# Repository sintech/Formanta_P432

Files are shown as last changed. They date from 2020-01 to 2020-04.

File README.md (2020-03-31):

# Форманта П432
инструкция ([djvu](docs/Formanta%20P432%20Users%20manual.djvu) | [pdf](docs/Formanta%20P432%20Users%20manual.pdf)), [схемы](schematic), [прошивки](roms) и [эмулятор](src).

Устройство для проверки узла генераторов - [Cхема PDF](kicad/OscTester/OscTester.pdf)

Инструкция по доработке узла генераторов до последней известной версии - [PDF](docs/Oscillator_board_upgrade_tips.pdf)

# Formanta P432 # 
[Manual](docs/Formanta%20P432%20Users%20manual.pdf), [schematic diagrams](schematic), [ROM dumps](roms) and [emulator](src).

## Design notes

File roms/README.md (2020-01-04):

## Узел генераторов ##
* **DD1.BIN**, **DD2.BIN** - частота-приращение
* **DD13.BIN**, **DD14.BIN**, **DD18.BIN**, **DD19.BIN** - волноформы
* **DD27.BIN**, **DD28.BIN** - масштабирование

## Узел процессора ##
**DD16.BIN** - ПО синтезатора, конфигурация тембров (с адреса 0x400).

## Узел МИДИ-интерфейса ##
**Midi_DD2.BIN** - подпрограммы МИДИ

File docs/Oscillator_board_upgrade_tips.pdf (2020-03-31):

## Инструкция по приведению узла генераторов Форманты П432 к последней

известной версии.

Известные мне печатные платы узла генераторов с децимальным номером ДПЮ 7.102.087 имеют следующие даты изготовления и заводские номера:

- П432, изм. 10, дата 04-91, №290 (ранняя версия, без платы ПНЧ (преобразователя напряжениечастота)
- П432, изм. 10, дата 10-91, №137-2 (с платой ПНЧ)
- П432, изм. 10, дата 11-91, №137-6 (с платой ПНЧ)
- П432, изм. 10, дата 12-91, №56-8 (с платой ПНЧ)
- П432, изм. 15, дата 09-92, №1143-2 (новая топология, с платой ПНЧ)
- МИНИ, изм. 14, дата 07-92, №881-14 (новая топология, с платой ПНЧ)

Существует минимум две версии топологии платы. Ранняя имеет следующие признаки:

- От анода VD12(обозначение на плате) идет дорожка к 6 выводу DD15 (перерезана)
- VT5-К, катод VD7 и левый вывод C18 соединены (может быть перерезано)
- Дорожка от DD29-5 до DD21-1 (может быть перерезана)

Список шагов актуален для версии узла генераторов с подключенной дочерней платой ПНЧ.

В приложении приведены фотографии плат с обозначением мест доработок.

### Список шагов

Удалить элементы:
1. Конденсаторы: C34(470uF), С35(H24), С36(n27), С10?
2. Транзистор VT5
3. Резисторы: R41(75к)? (34к у меня), R38(68к)
4. Подстроечный резистор R64 (баланс DA49).
5. Диод поверх R36 (черная полоса к DA49).

Перерезать дорожки:
1. Над R43, соединяющую DA38-18 и VT5-Б
2. Соединяющую DD47-8 и R66
3. Соединяющую катод VD12(обозначение на плате) и DD15-6
4. Соединяющую VT5-К, катод VD7 и левый вывод C18.
5. Соединяющую DD29-5 и DD21-1.
6. Между соединением R66 и R40 (на обратной стороне)
7. Соединяющую DD46-16 и +5В (обратная сторона)
8. Соединяющую DD47-10 и C18+VT5-Э (обратная сторона)
9. От шины земли до DD39-10 (обратная сторона)
10. Соединяющую R14 и DA17-6 (обратная сторона)
11. Соединяющую DD21-1 и DD21-5 (обратная сторона)

Добавить элементы:
1. Добавить резистор 330Ом от DD46-16 до +5В (с обратной)
2. Резистор (R71) 47к между DD39-7(GNDD) и DD39-10. Конденсатор (С40) 10мкФ между DD39-10 и +5В.
3. Резистор 100кОм в точки, где стоял проволочный фиксатор C34.
4. Транзистор VT5 – КТ3102, развернув его на 180о относительно старого.
5. Конденсатор 68нФ от соединения R41+C35+C36 до точки R41+DA49-3.

6. Конденсатор 270пФ поверх R39.
7. Транзистор КП103Е. Исток – DA49-2(1 вывод R38), сток – DA47-3(2 вывод R38), затвор – R41+C35.
8. Заменить R66 на 33кОм.

Установить перемычки на обратной стороне платы:
1. От соединения R26 и R23 до DA48-4 (заводская?, может быть сверху)
2. От катода VD12 до DD29-5
3. Катод VD7 до DA41-3
4. От R14 (со стороны пореза) до катода VD9(напротив DD21-1) + R65 + R12.
5. От DD47-10 до DD47-8+C18+VT5-К
6. От точки 35 (Усилитель ОУ0) до свободного вывода R66
7. От свободного вывода R40 до + бывшего С34 (+5В)
8. От соединения C36, C35 до первого вывода резистора 100к, от второго вывода до C18+VT5-Э
9. DD21-5 и DD29-5 (к ноге R67)

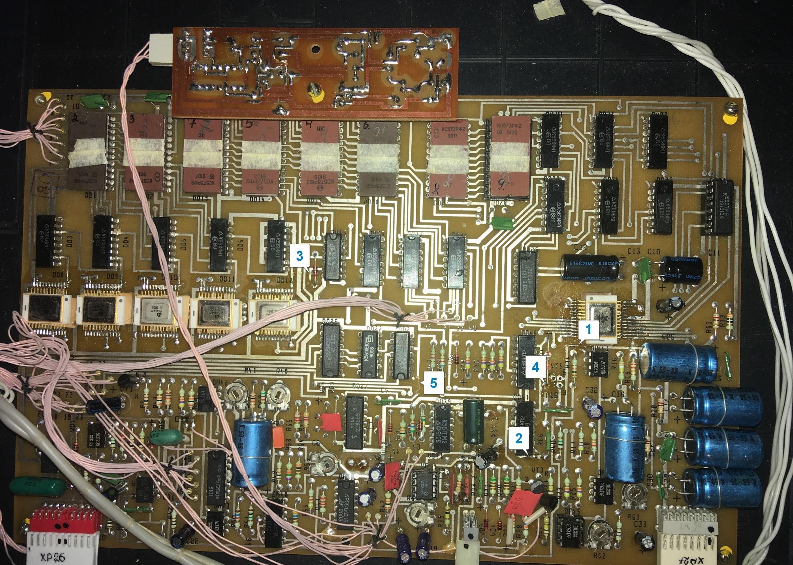
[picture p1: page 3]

### Приложение

Перерезать дорожки сверху

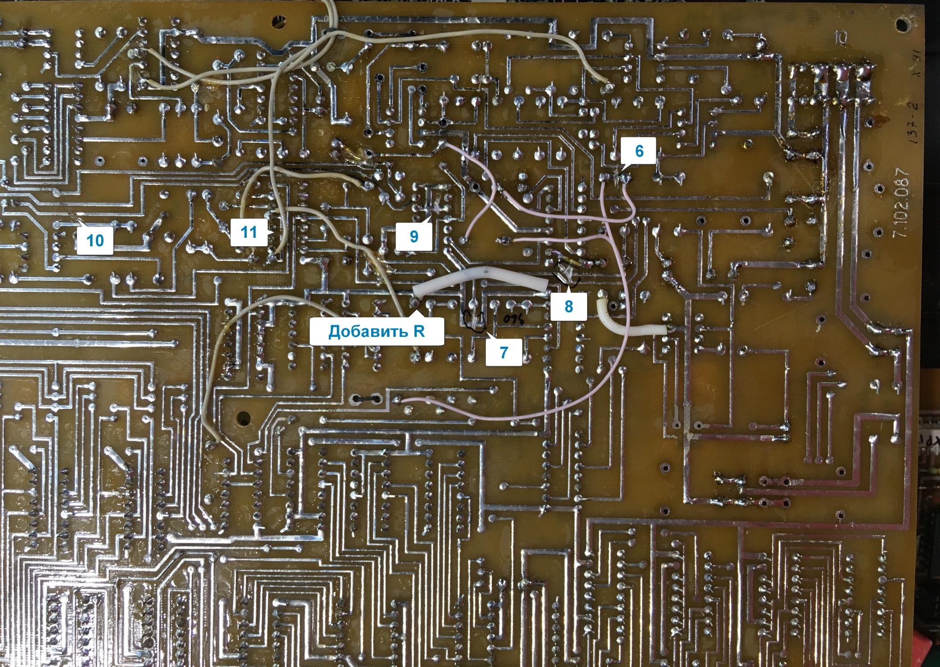
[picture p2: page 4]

Перерезать дорожки снизу

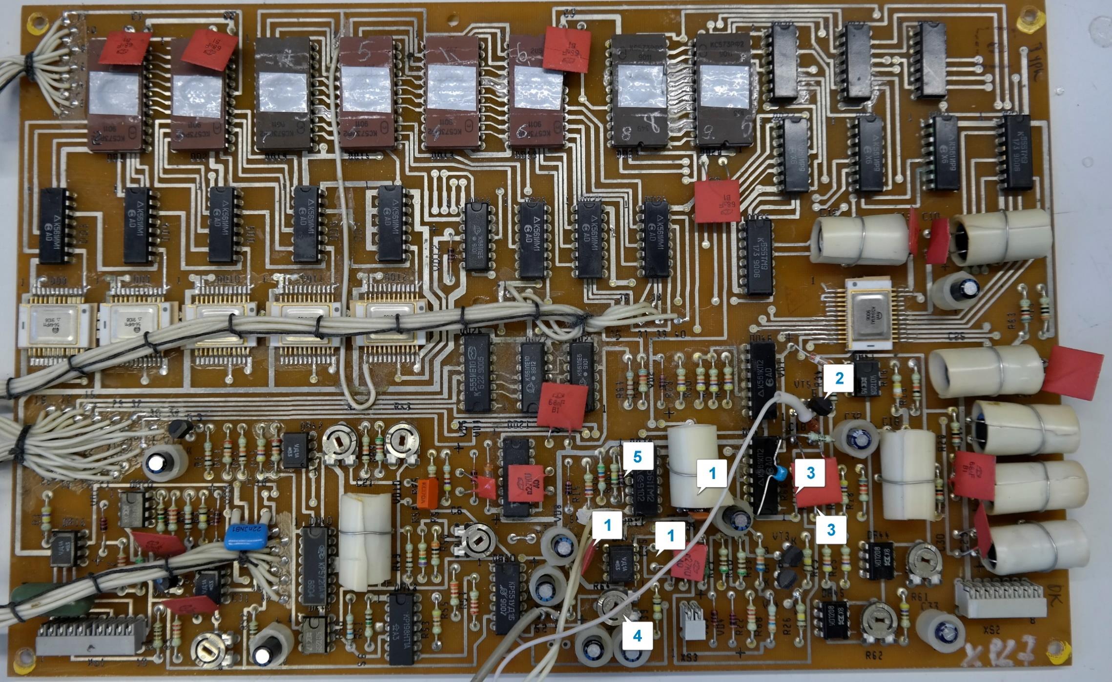
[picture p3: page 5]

Удалить элементы

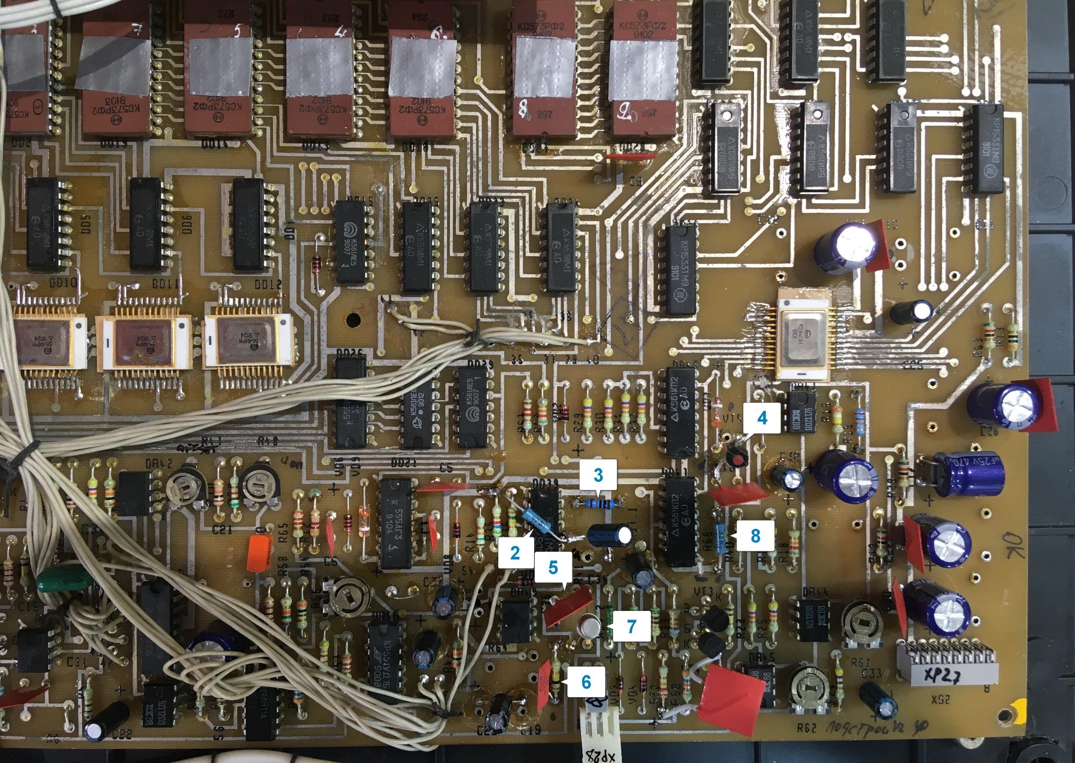
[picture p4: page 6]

Добавить элементы

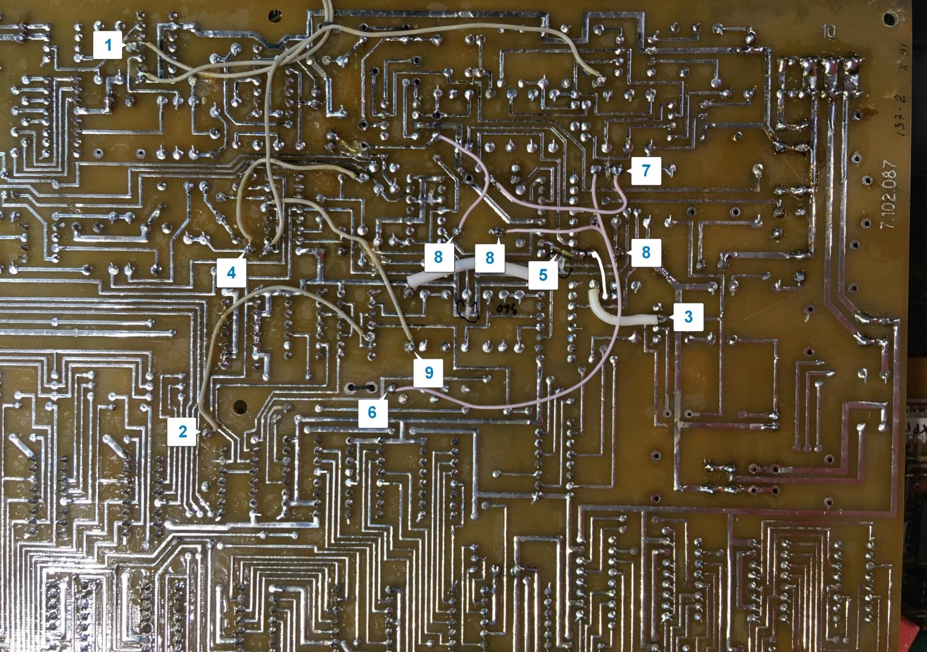
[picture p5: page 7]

Установить перемычки на обратной стороне платы

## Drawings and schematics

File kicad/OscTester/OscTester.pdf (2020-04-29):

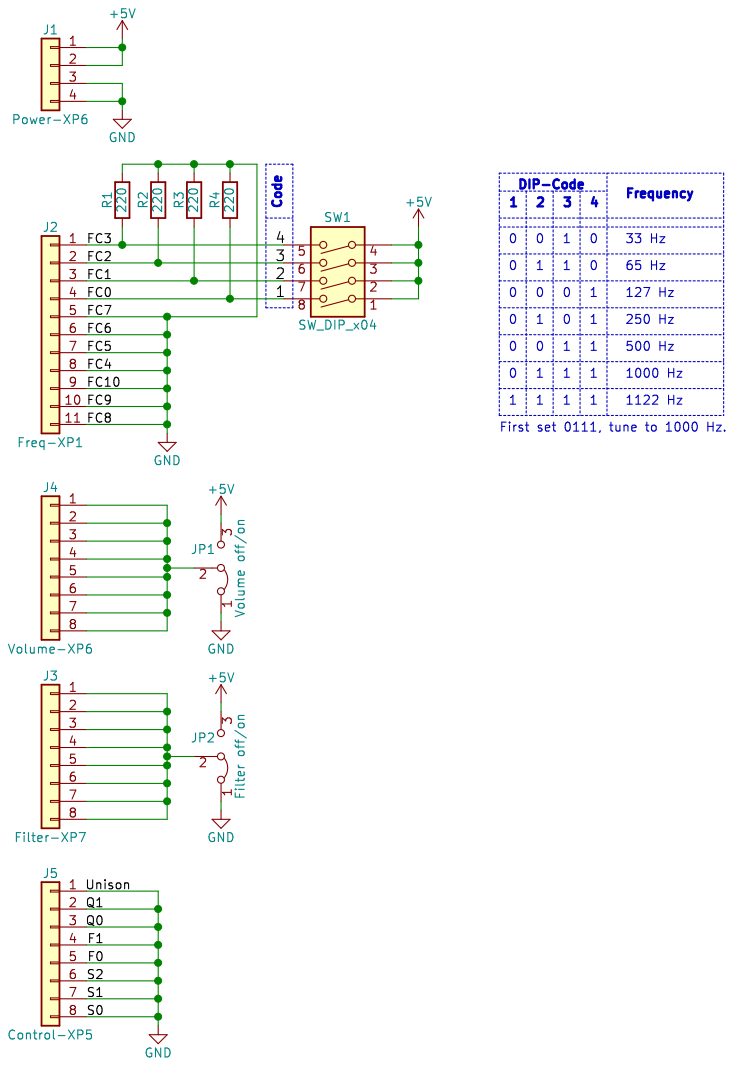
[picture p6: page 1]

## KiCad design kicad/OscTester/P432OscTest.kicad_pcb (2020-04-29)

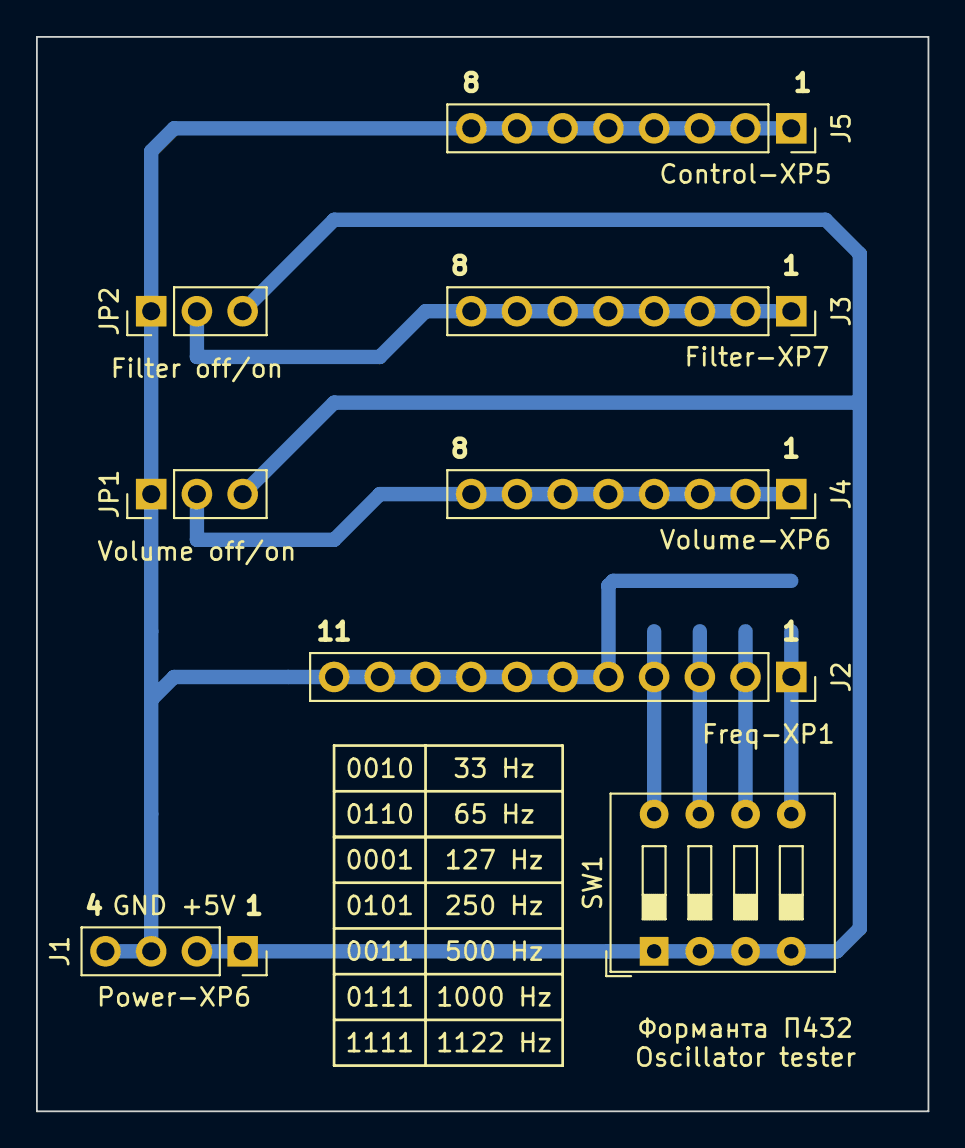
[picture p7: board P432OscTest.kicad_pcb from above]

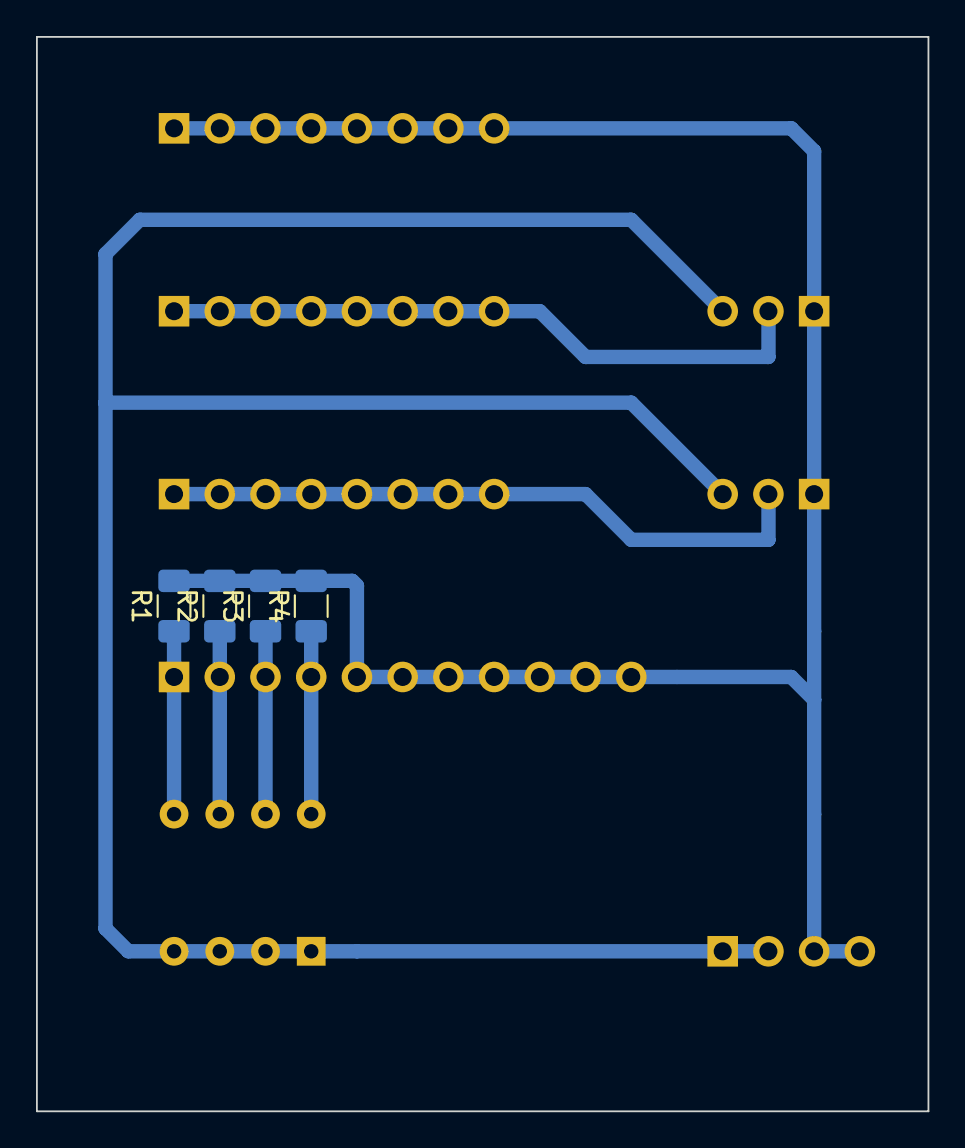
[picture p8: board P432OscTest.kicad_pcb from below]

Board: 2 copper layers, 49.5 x 59.7 mm, 12 parts (4 on the bottom side), 8 nets.

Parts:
J1: Power-XP6; PinSocket_1x04_P2.54mm_Vertical
J2: Freq-XP1; PinSocket_1x11_P2.54mm_Vertical
J3: Filter-XP7; PinSocket_1x08_P2.54mm_Vertical
J4: Volume-XP6; PinSocket_1x08_P2.54mm_Vertical
J5: Control-XP5; PinSocket_1x08_P2.54mm_Vertical
JP1: Volume off/on; PinHeader_1x03_P2.54mm_Vertical
JP2: Filter off/on; PinHeader_1x03_P2.54mm_Vertical
R1, R2, R3, R4: 220; R_1206_3216Metric
SW1: SW_DIP_x04; SW_DIP_SPSTx04_Slide_9.78x12.34mm_W7.62mm_P2.54mm

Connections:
+5V: J1.1, J1.2, JP1.3, JP2.3, SW1.1, SW1.2, SW1.3, SW1.4
/1: J2.4, R4.1, SW1.8
/2: J2.3, R3.1, SW1.7
/3: J2.2, R2.1, SW1.6
/4: J2.1, R1.1, SW1.5
GND: J1.3, J1.4, J2.5, J2.6, J2.7, J2.8, J2.9, J2.10, J2.11, J5.1, J5.2, J5.3, J5.4, J5.5, J5.6, J5.7, J5.8, JP1.1, JP2.1, R1.2, R2.2, R3.2, R4.2
unnamed: J3.1, J3.2, J3.3, J3.4, J3.5, J3.6, J3.7, J3.8, JP2.2
unnamed: J4.1, J4.2, J4.3, J4.4, J4.5, J4.6, J4.7, J4.8, JP1.2

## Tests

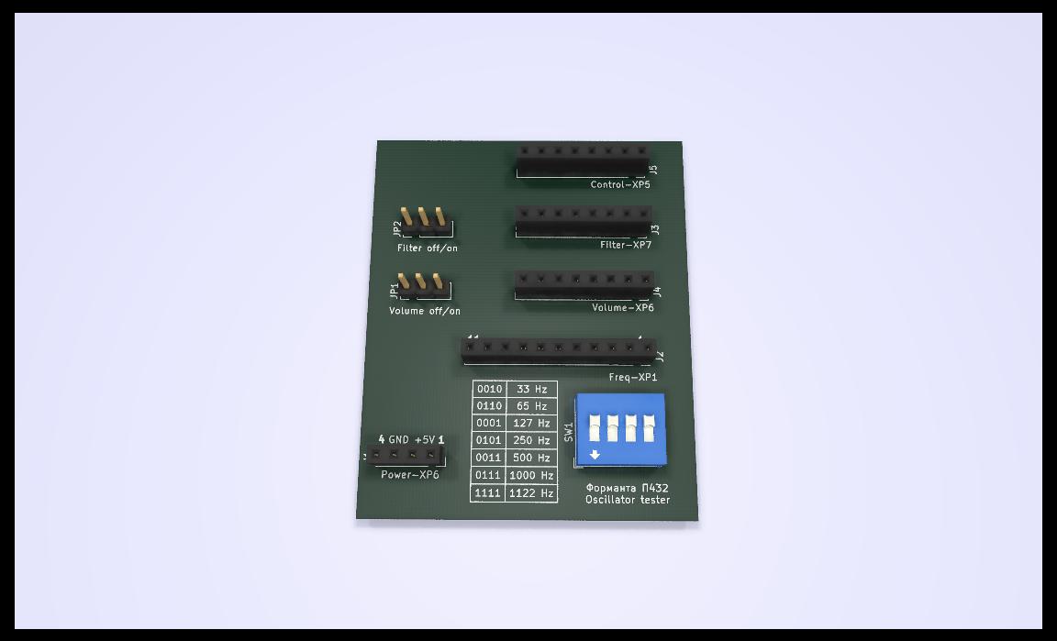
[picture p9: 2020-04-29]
kicad/OscTester/P432OscTest.jpg

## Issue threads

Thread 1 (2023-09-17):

Noises

GarryGNsk, 2023-09-17:
Здравствуйте! Ремонтирую данный прибор. Беспокоит шумность. У вас случайно нет схемы крайней ревизии, которая меньше шумит. Делать мод по инструкции без схемы не решаюсь.
Буду очень признателен. Моя почта timgv@mail.ru.
В Вашем эмуляторе на окончании звуков тоже слышны цифровые шумы, я так понимаю что совсем от них не избавиться с этой схемой. Спасибо

sintech, 2023-09-17:
Ответил в почту

Closed 2023-09-17.

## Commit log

2020-03-31 Oscillator board upgrade tips
2020-03-31 Oscillator tester
    [P432OscTest.kicad_pcb, P432OscTest.sch]
2020-03-31 pcb fix
    [P432OscTest.kicad_pcb]
2020-04-21 Unison bit set to 0 to test all 8 voices
    [P432OscTest.kicad_pcb, P432OscTest.sch]
2020-04-29 Freq values changed to the correct ones.
    [P432OscTest.kicad_pcb, P432OscTest.sch]
